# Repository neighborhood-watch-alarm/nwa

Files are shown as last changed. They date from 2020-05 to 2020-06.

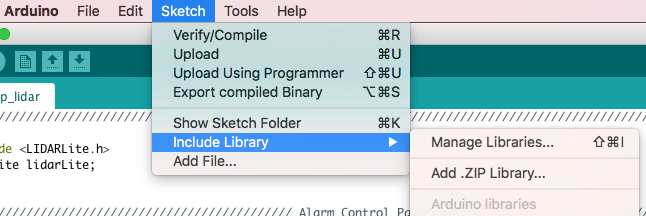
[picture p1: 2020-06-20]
site/frontend/src/Images/arduino-lib-man.png

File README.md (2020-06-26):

# Neighborhood Watch Alarm (NWA)
NWA is an open source neighborhood security movement with an alarm system that anyone can assemble and manage locally. NWA is published under the [MIT License](https://github.com/neighborhood-watch-alarm/nwa/blob/master/LICENSE).

The client-server system consists of Arduino-based **alarms** outfitted with sensors, and a Raspberry Pi **server**. The devices communicate via LoRa signals and a TTN Gateway. The server sends text-messages when an alarm is triggered.

For general and installation related information, please see the [**main site**](https://nwa-site.herokuapp.com/).

For system details and architecture descriptions, please see the [wiki](https://github.com/neighborhood-watch-alarm/nwa/wiki).

# Code Status

Accepted source code for the server and the website goes through a **Continues Integration** pipeline using *Github Actions*.

The current status for the different pipelines can be seen below:

Server status:



Frontend status:



Backend status:



# Current Project Team Members
* [mikkelgthang](https://github.com/mikkelgthang)
* [simoneengelbr](https://github.com/simoneengelbr)

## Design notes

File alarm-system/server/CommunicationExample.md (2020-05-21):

Every N time period
Sensor sends uplink:
{
	armStatus : boolean,
}
Response:
Backend responds with downlink
{
	armStatus : boolean
}

IF a trigger occurs on a sensor that is not a panic alarm:
Sensor sends uplink:
{
	tripped : true,
	panic : false
}
Response:
Backend responds with downlink
{
	armStatus : boolean
}
IF a trigger occurs on a sensor that is  a panic alarm:

input: Panic Alarm is triggered
Sensor sends uplink:
{
	tripped	  : boolean
	panic : true
}

Response:
Backend starts alarming everyone.

When the keypad has a code enterred
Keypad sends uplink:
{
	password : string
}
Response:
Backend sends downlink
{
	response : boolean
}

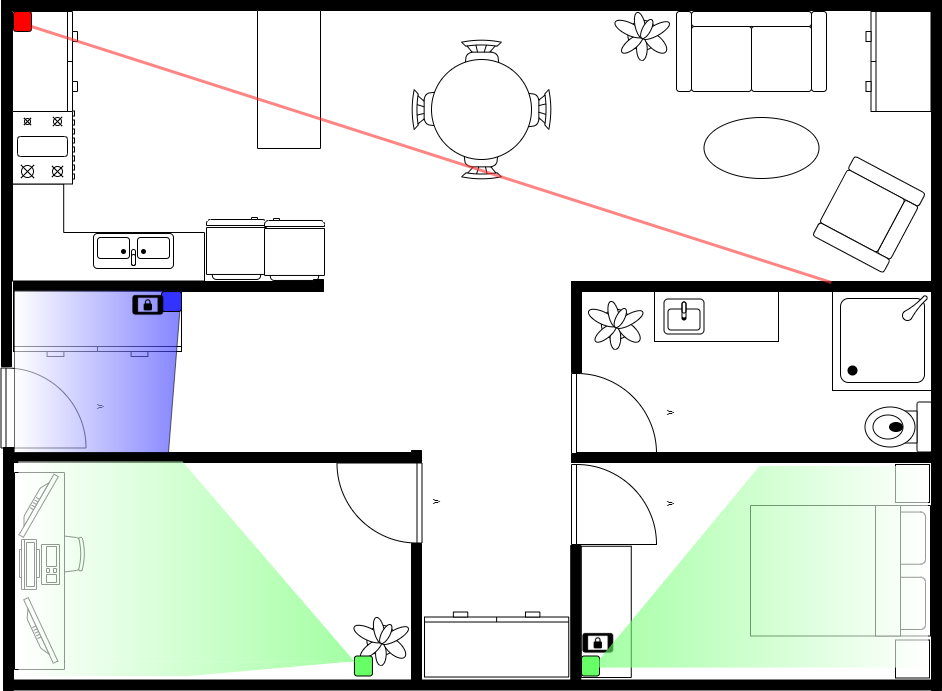
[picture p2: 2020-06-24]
site/frontend/src/Images/alarmDesign-example.png

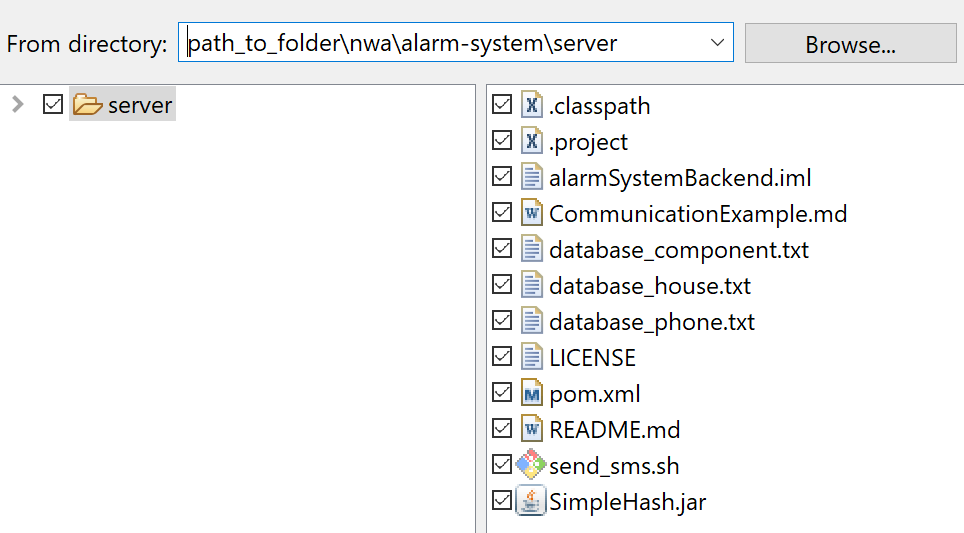
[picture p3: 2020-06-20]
site/frontend/src/Images/importEclipse.png

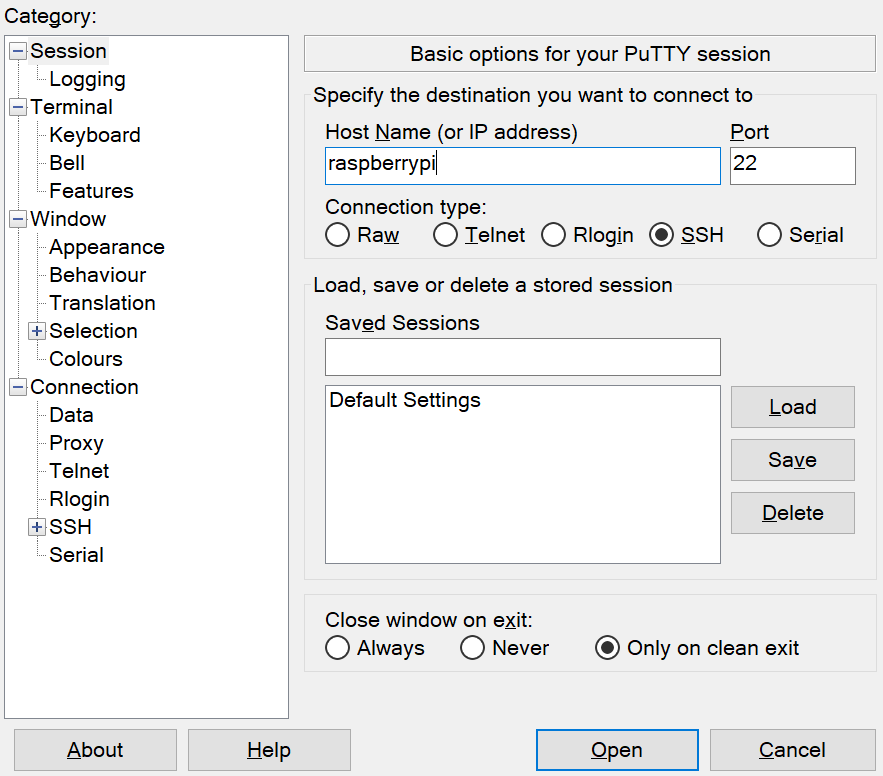
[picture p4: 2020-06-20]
site/frontend/src/Images/putty.png

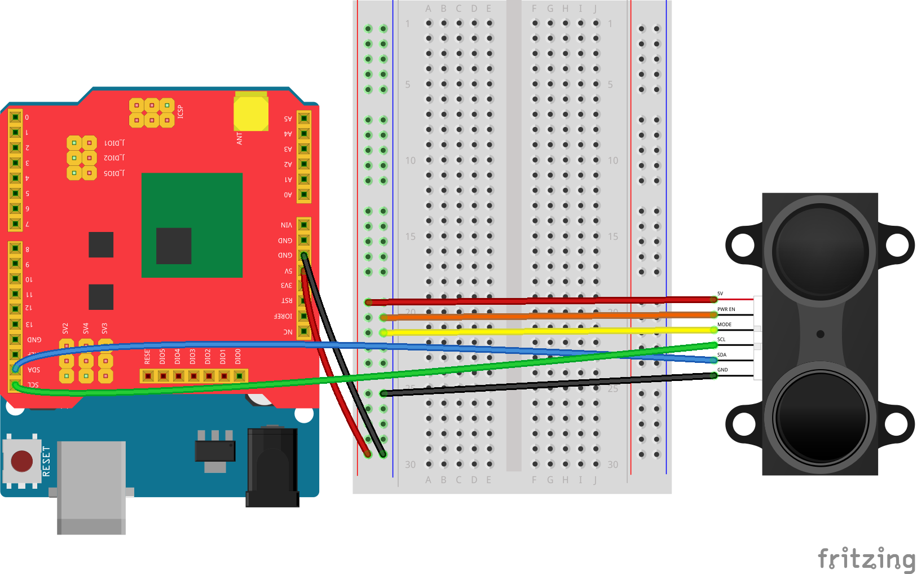
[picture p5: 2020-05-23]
site/frontend/src/Images/Fritzing/Images/NodeLIDAR.png

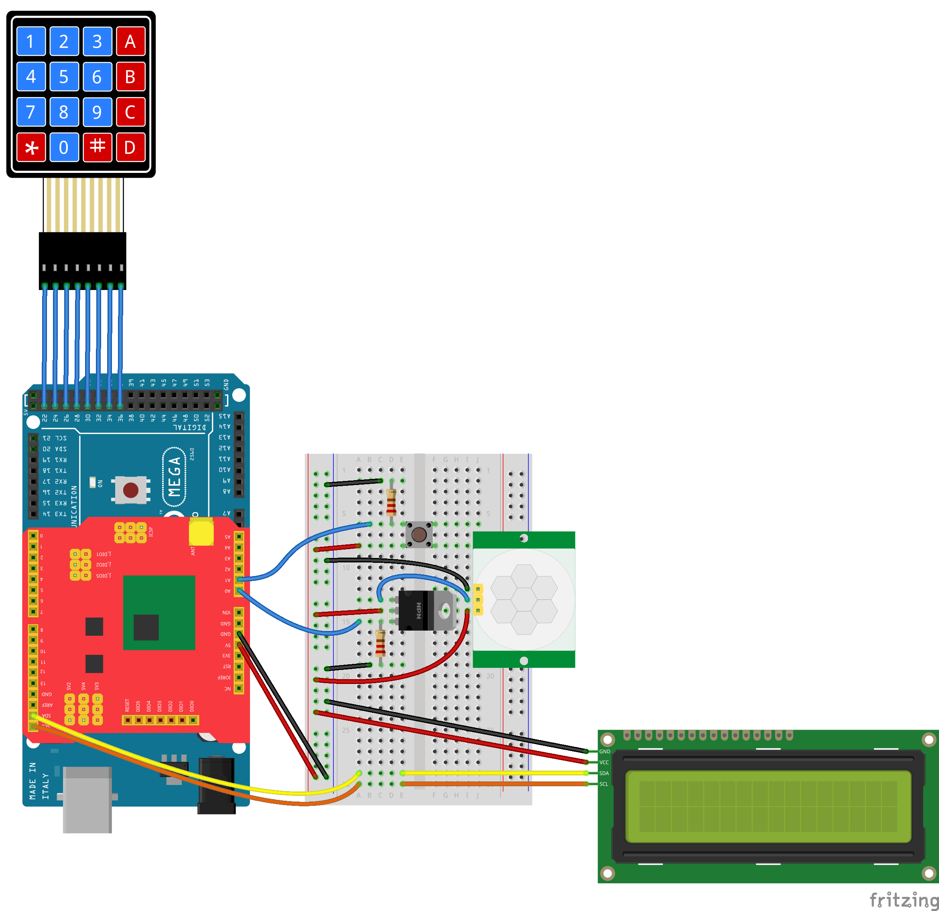
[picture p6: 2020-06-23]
site/frontend/src/Images/Fritzing/Images/ControlPIR.png

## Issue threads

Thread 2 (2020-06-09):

Implement a panic button (sensor) node

simoneengelbr, 2020-06-09:
This issue is recommended for developers with minor experience with Arduino and software development. The issue will act as an introduction to the alarm setup and installation documentation.

Implement a sensor node with a panic button instead of a sensor. This way a panic button can be installed in the home independently of a control panel.

A panic button is installed on every control panel, and uses a breadboard. No sensor node uses a panic button at this time. Sensor nodes do, however, have a 'panic flag' value, it is just never updated. This sensor node will read a panic button instead of a sensor. The setup will include an Arduino UNO with a LoRa-shield, sonnected to a panic button at the A0 pin (in place of a sensor).

First the sensor node setup must be created:
- Locate code used for panic button in the [control panel files](https://github.com/simoneengelbr/nwa/tree/master/alarm-system/alarm/control-panel):
(https://github.com/simoneengelbr/nwa/blob/fa6ef3e4ad63f8c5d1ab571c24c9136e11122889/alarm-system/alarm/control-panel/Alarm_control_panel_Lidar.ino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)
   - How to read the pin: [link](https://github.com/simoneengelbr/nwa/blob/fa6ef3e4ad63f8c5d1ab571c24c9136e11122889/alarm-system/alarm/control-panel/Alarm_control_panel_Lidar.ino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)
   - When to read the pin and update panic status: [link](https://github.com/simoneengelbr/nwa/blob/fa6ef3e4ad63f8c5d1ab571c24c9136e11122889/alarm-system/alarm/control-panel/Alarm_control_panel_Lidar.ino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)
- Create sensor node code
   - Duplicate [sensor node file](https://github.com/simoneengelbr/nwa/tree/master/alarm-system/alarm/sensor-node) of your choice
   - Add code used for panic button where it was in control panel code
   - Remove code used for sensor (sensor setup, sensor specific loop code, sensor specific loop code - indicated with comments)
   - Notice that both pin A0 and pin A1 [are activated on setup](https://github.com/simoneengelbr/nwa/blob/fa6ef3e4ad63f8c5d1ab571c24c9136e11122889/alarm-system/alarm/sensor-node/Sensor_node_Lidar.ino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). Only one is needed for the panic button, so remove A1. Then make sure to change which pin is read in the panicButton()-method, in the analogRead()-call.

If you have hardware available, now is a great time to test your implementation.

Then, documentation of the new sensor node must be added to the installation guide on the nwa website:
- Create a [fritzing](https://fritzing.org/download)-diagram of the new sensor node, inspired by the files used for a control panel and a sensor node:
[Fritzing-examples.zip](https://github.com/simoneengelbr/nwa/files/4753516/Fritzing-examples.zip)
- Website update: TBA

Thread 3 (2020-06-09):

Triggering of ultrasonic sensor

simoneengelbr, 2020-06-09:
The alarm setups that use an ultrasonic sensor have too high of a threshold for movement measurements, and is consequently difficult to trigger. This needs to be fixed.

Tasks:
- Review the sensor specific loop code used for the ultrasonic sensor today
- Test an ultrasonic sensor and determine how to edit the sensor specific loop code so the alarm is triggered more easily (but be careful to avoid false alarms)
- Finally, update the sensor specific loop code of the ultrasonic sensor node and the ultrasonic control panel to include your edits of the sensor specific loop code

Closed 2020-06-09.

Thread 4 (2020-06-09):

Refine triggering of ultrasonic sensor

simoneengelbr, 2020-06-09:
The alarm setups that use an ultrasonic sensor have too high of a threshold for movement measurements, and is consequently difficult to trigger. This needs to be fixed.

Tasks:
- Review the sensor specific loop code used for the ultrasonic sensor today
- Test an ultrasonic sensor and determine how to edit the sensor specific loop code so the alarm is triggered more easily (but be careful to avoid false alarms)
- Finally, update the sensor specific loop code of the ultrasonic sensor node and the ultrasonic control panel to include your edits of the sensor specific loop code

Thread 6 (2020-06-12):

Fix arduino workflow

simoneengelbr, 2020-06-12:

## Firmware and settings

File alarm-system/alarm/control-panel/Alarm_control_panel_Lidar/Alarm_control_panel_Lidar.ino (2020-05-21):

//////////////////////////////////////////////// Sensor setup ///////////////////////////////////////////////////////////////////////////

#include <LIDARLite.h>
LIDARLite lidarLite;


//////////////////////////////////////////////// Alarm Control Panel setup ///////////////////////////////////////////////////////////////////////////

#include <LiquidCrystal_I2C.h>
#include <Keypad.h>
#include "SipHash_2_4.h"

uint8_t hashKey[] = {0x00, 0x01, 0x02, 0x03, 0x04, 0x05, 0x06, 0x07, 0x08, 0x09, 0x0a, 0x0b, 0x0c, 0x0d, 0x00, 0x00};

const byte ROWS = 4;
const byte COLS = 4;

char hexaKeys[ROWS][COLS] = {
  {'1', '2', '3', 'A'},
  {'4', '5', '6', 'B'},
  {'7', '8', '9', 'C'},
  {'*', '0', '#', 'D'}
};

byte rowPins[ROWS] = {22, 24, 26, 28};
byte colPins[COLS] = {30, 32, 34, 36};

char keypadList[] = {'x','x', 'x', 'x'}; 
int keypadCnt = 0;

Keypad keypad = Keypad(makeKeymap(hexaKeys), rowPins, colPins, ROWS, COLS);

LiquidCrystal_I2C lcd(0x27, 1, 2);  



//////////////////////////////////////////////// LMIC and common setup ///////////////////////////////////////////////////////////////////////////

#include <EEPROM.h>
#include <Wire.h> 

int cal_cnt = 0;
int refDist = -1;
int distCnt = 0;
int pwFlag = 0;
int panicFlag = 0;
int armFlag = 0;
int alarmFlag = 0;

#include <lmic.h>
// MIT License
// https://github.com/gonzalocasas/arduino-uno-dragino-lorawan/blob/master/LICENSE
// Based on examples from https://github.com/matthijskooijman/arduino-lmic
// Copyright (c) 2015 Thomas Telkamp and Matthijs Kooijman


#include <hal/hal.h>


// Initialise short and long payloads. The last byte is dead and is never received.
uint8_t shortMessage[] = {1, 1, 1, 99};
uint8_t longMessage[] = {1, 1, 1, 4, 5, 6, 7, 8, 9, 10, 11, 12, 13, 14, 15, 16, 17, 18, 19, 99}; // unused by sensor nodes

int t_start = 0;
int t_wait = 10000; // time in ms to wait until sensors activate to guarantee correct calibration

static const u1_t NWKSKEY[16] = { 0x6E, 0xA5, 0xD8, 0x03, 0x4C, 0xB7, 0xBB, 0x93, 0x65, 0xBB, 0xDE, 0x95, 0x1D, 0x2F, 0x01, 0x3B };
static const u1_t APPSKEY[16] = { 0x31, 0x52, 0x01, 0x40, 0x8A, 0xAE, 0x74, 0xDE, 0x59, 0x03, 0x49, 0xC0, 0x4A, 0x41, 0x88, 0x7D };
static const u4_t DEVADDR = 0x26011C80;

// The LMIC library requires that these variables are set, but they are not used.
void os_getArtEui (u1_t* buf) { }
void os_getDevEui (u1_t* buf) { }
void os_getDevKey (u1_t* buf) { }

static osjob_t sendjob;


// Delay in seconds between TX ending and starting new TX
int TX_delay = 150;

// Pin mapping for using the Dragino Shield
const lmic_pinmap lmic_pins = {
    .nss = 10,
    .rxtx = LMIC_UNUSED_PIN,
    .rst = 9,
    .dio = {2, 6, 7},
};

void onEvent (ev_t ev) {
    Serial.print("ev: ");
    Serial.println(ev);
    switch(ev) {
      case EV_TXCOMPLETE:
        Serial.println("TX + RX windows complete");
        Serial.println(LMIC.seqnoUp);
        if (LMIC.dataLen) {
            Serial.print(F("Data received - "));
            Serial.print("frame: ");
            Serial.write(LMIC.frame, 2);
            Serial.print(", dataBeg: ");
            Serial.print(LMIC.dataBeg);
            Serial.print(", len: ");
            Serial.println(LMIC.dataLen);
            Serial.print("all: ");
            Serial.write(LMIC.frame + LMIC.dataBeg, LMIC.dataLen);
            Serial.println();
            Serial.println(LMIC.frame[LMIC.dataBeg+0]);
            Serial.println(LMIC.frame[LMIC.dataBeg+1]);
            Serial.println(LMIC.frame[LMIC.dataBeg+2]);

          // The value 0 introduces weird errors when using TTN. For payload 1 is false and 2 is true.
          if (LMIC.frame[LMIC.dataBeg+0] == 2) {

            if (armFlag == 0) {
              lcd.setCursor(0,1);
              lcd.print("Armed           ");

              // Calibrate sensor
              refDist = getRefDist();
            }
            armFlag = 1;
          }
          else if (LMIC.frame[LMIC.dataBeg+0] == 1) {
            if (armFlag == 1) {
              lcd.setCursor(0,1);
              lcd.print("Disarmed        ");
            }
            armFlag = 0;
          }

          if (LMIC.frame[LMIC.dataBeg+1] == 1) {
            panicFlag = 0;
          }
            
        }   
        eepromUpdate();
        // Set time for next TX
        os_setTimedCallback(&sendjob, os_getTime()+sec2osticks(TX_delay), do_send);
        break;
      default:
        Serial.print("ev: ");
        Serial.println(ev);
        break;
    }
}

void do_send(osjob_t* j){
    // Update uplink TX payload
    
    // Update iff there isn't currently a TX happening
    if (!(LMIC.opmode & OP_TXRXPEND)) {
        // The value 0 introduces weird errors when using TTN. For payload 1 is false and 2 is true.
        
        // Arm status
        shortMessage[0] = armFlag + 1;
        longMessage[0] = armFlag + 1;

        // Panic status
        shortMessage[1] = panicFlag + 1;
        longMessage[1] = panicFlag + 1;

        // Alarm status
        shortMessage[2] = alarmFlag + 1;
        longMessage[2] = alarmFlag + 1;
        
        // Set payload message to include hash of the entered password, if '#' has been pressed on the keypad
        if (pwFlag == 1) {
          LMIC_setTxData2(1, longMessage, sizeof(longMessage)-1, 0);
          pwFlag = 0;
        }
        // Otherwise just use the short payload format to reduce airtime
        else {
          LMIC_setTxData2(1, shortMessage, sizeof(shortMessage)-1, 0);
        }
        Serial.println("Sending uplink TX");
    }
}

void eepromUpdate() {
  // Convert frame counters up and down to two byte each so they can be stored in EEPROM
  byte upHigh = (LMIC.seqnoUp & 0xFF00) / 256;
  byte upLow = LMIC.seqnoUp & 0x00FF;
  byte dnHigh = (LMIC.seqnoDn & 0xFF00) / 256;
  byte dnLow = LMIC.seqnoDn & 0x00FF;
  EEPROM.write(0, upHigh);
  EEPROM.write(1, upLow);
  EEPROM.write(2, dnHigh);
  EEPROM.write(3, dnLow);
  Serial.println("EEPROM:");
  Serial.println(upHigh);
  Serial.println(upLow);
  Serial.println(dnHigh);
  Serial.println(dnLow);
}

//////////////////////////////////////////////// LMIC and common setup ///////////////////////////////////////////////////////////////////////////



void setup(){
  Serial.begin(9600);
  Serial.println("booting");

  pinMode(A0, INPUT);
  pinMode(A1, INPUT);
  
  t_start = millis();

  // Initialise LMIC
  os_init();
  LMIC_reset();
  LMIC_setSession (0x1, DEVADDR, NWKSKEY, APPSKEY);
  LMIC_setLinkCheckMode(0);

  // This is increased from 1/100 to avoid losing downlink payload
  LMIC_setClockError(MAX_CLOCK_ERROR * 10 / 100); 

  // Downlink datarate. TTN uses SF9 for the RX2 window
  LMIC.dn2Dr = DR_SF9;

  // Uplink datarate is set to SF7 to reduce airtime as much as possible
  LMIC_setDrTxpow(DR_SF12,14);


  // Read frame counters from non-volatile memory
  byte eeprom0 = EEPROM.read(0);
  byte eeprom1 = EEPROM.read(1);
  byte eeprom2 = EEPROM.read(2);
  byte eeprom3 = EEPROM.read(3);

  // Update frame counters up and down iff EEPROM hasn't been reset
  if (eeprom0 != 255 && eeprom1 != 255 && eeprom2 != 255 && eeprom3 != 255) {
    Serial.println("Reading frame counters from EEPROM");
    LMIC.seqnoUp = eeprom0*256 + eeprom1;
    LMIC.seqnoDn = eeprom2*256 + eeprom3;
  }

  // Send first message
  do_send(&sendjob);

/////////// Device specific setup here ///////////

    // Initialise lcd
  lcd.init(); 
  lcd.backlight();
  lcdReset();

  // Initialise keypad
  keypad.addEventListener(keypadPress);
} 

void loop(){
  os_runloop_once();

  
 if ( millis() > t_start + t_wait) {

    ////////////////// Sensor specific loop code here //////////////////
    
    if (refDist == -1) {
      refDist = getRefDist();
    }

    int dist;
 
    // Correct for receiver bias every 100 reads
    if ( cal_cnt == 0 ) {
      dist = lidarLite.distance();      // With bias correction
    } else {
      dist = lidarLite.distance(false); // Without bias correction
    }
  
    // Increment read counter
    cal_cnt++;
    cal_cnt = cal_cnt % 100;

    if (dist > refDist + 30 || dist < refDist - 30) {
      distCnt+=3;
    }
    else if (dist > refDist + 10 || dist < refDist - 10) {
      distCnt++;
    }
    else {
      if (distCnt > 0) {
        distCnt--;
      }
    }
    if (distCnt >= 10 && armFlag == 1) {
      Serial.println("ALARM!");
      distCnt = 0;
      alarmFlag = 1;
    }
  }
  ////////////////////////////////////////////////////////////////////
  
  // Use keypad
  char customKey = keypad.getKey();  

  // Use panic button 
  if (panicButton() && panicFlag == 0) {
    panicFlag = 1;
        
    // Write to lcd
    lcd.clear();
    lcd.setCursor(0,0);
    lcd.print("Panic mode");
    lcd.setCursor(0,1);
    lcd.print("Activated");
  }
}

////////////////// Alarm Control Panel functions for LCD and keypad //////////////////

void lcdReset() {
  // Reset lcd
  lcd.clear();
  lcd.setCursor(0,0);
  lcd.print("Enter pw:        ");
  lcd.setCursor(0,1);
  lcd.print("Disarmed         ");
}

void keypadPress(KeypadEvent kpp) {
  switch(keypad.getState()) {
    case PRESSED:
    char kpInput = kpp;
    lcd.setCursor(14, 2); 
    lcd.print(kpInput);
    Serial.print(keypadCnt);
    Serial.print(", ");
    Serial.println(kpInput);

    switch(kpInput) {
      case '*':
        // Delete entered password
        keypadCnt = 0;
        lcd.setCursor(9,0);
        lcd.print("       ");
        break;
      case '#':
        // Submit password
        if (keypadCnt == 4) {
          hashKey[14] = (byte) EEPROM.read(0);
          hashKey[15] = (byte) EEPROM.read(1);
          sipHash.initFromRAM(hashKey);

          Serial.println("Keypad input as int: ");
          
          for (int i=0; i<4;i++) {
            sipHash.updateHash((byte)keypadList[i]); // update hash with each byte of msg
            Serial.println((byte)keypadList[i]);
          }
          sipHash.finish();
          for(int i=0; i<16;i++) {
            longMessage[i+3] = sipHash.result[i];
          }
          
          pwFlag = 1;

          // Write to lcd
          lcd.setCursor(0,1);
          lcd.print("Waiting for ack.");

          // reset entered password
          keypadCnt = 0;
          lcd.setCursor(9,0);
          lcd.print("       ");
        }
        break;
      case 'A':
        break;
      case 'B':
        break;
      case 'C':
        break;
      case 'D':
        break;
      case '0' ... '9':
        if (keypadCnt <= 3) {
          keypadList[keypadCnt] = kpInput;
          lcd.setCursor(9+keypadCnt,0);
          lcd.print('*');
          keypadCnt++;
        }
        break;
    }
  }
}

bool panicButton() {
  if (analogRead(1) > 900) {
    Serial.println("Panic button pressed");
    return true;
  }
  else {
    return false;
  }
}

////////////////// Sensor specific non-loop code here //////////////////
  
int getRefDist() {
    //#######################################
    // for Lidar
    lidarLite.begin(0, true);   
    lidarLite.configure(0); 
  
    int distSum = 0;
    for (int i=0; i<99; i++) {
      distSum = distSum + lidarLite.distance();
    }
    distSum = distSum + lidarLite.distance(false);
    distSum = distSum / 100;
    Serial.print("refDist = ");
    Serial.print(distSum);
    Serial.println(" cm");
    //#######################################
    return distSum;
}

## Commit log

2019-06-03 Added Disappearing Devices
2019-06-05 small timerFix
2019-06-06 Removed println
    Removed unnessecary println
2020-05-23 site graphics initial commit
    [BasicControl.fzz, ControlBasic.fzz, ControlLIDAR.fzz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]
2020-05-27 Sample setup working
2020-05-27 Switching around again
2020-05-28 Edited for ultrasonic handling
2020-06-11 Fritzing files uploaded
    [BasicControl.fzz, ControlBasic.fzz, ControlLIDAR.fzz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]
2020-06-19 File cleanup
    [BasicControl.fzz, ControlBasic.fzz, ControlLIDAR.fzz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]
2020-06-20 Finished server files without translations
    [BasicControl.fzz, ControlBasic.fzz, ControlLIDAR.fzz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]
2020-06-23 further guide work
    [ControlPIR.fzz, NodeBasic.fzz, NodePIR.fzz]
